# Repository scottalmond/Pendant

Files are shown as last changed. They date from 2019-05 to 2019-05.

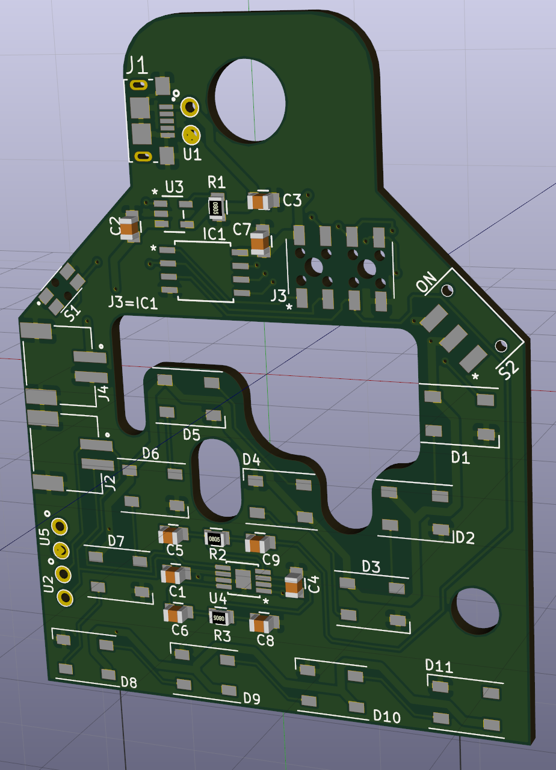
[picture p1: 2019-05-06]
src/layout_front.png

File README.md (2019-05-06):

# Pendant

The purpose of this project is to develop a piece of artisan eletronics to serve as a prize for an eletronics competition.  The design consists of a PCB and 3D-printed case.  The CAD model for the case has been excluded from this project because it incorporates proprietary elements.

Development Tools
Arduino IDE
KiCAD
FreeCAD

The J3 header has a 1:1 pinout matching the Attiny85 processor.
Instructions for programming the Attiny85 using an Arduino is documented at the start of the Arduino code.  Once the Arduino has been programmed with the ArduinoAsISP program, it can be connected to the J3 programming header using the following connections:
https://hackster.imgix.net/uploads/cover_image/file/50546/Programming%20ATtiny85%20with%20Arduino%20Uno_bb.png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

License
CC BY 4.0: Scott Almond
https://creativecommons.org/licenses/by/4.0/

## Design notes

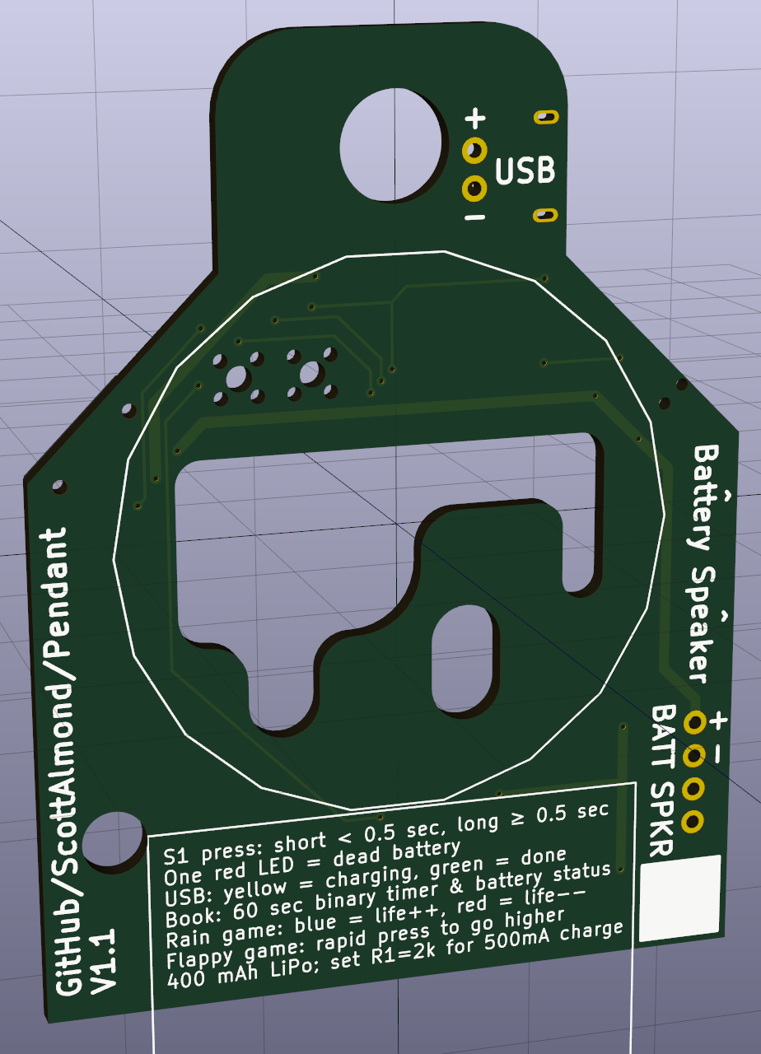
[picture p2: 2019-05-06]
src/layout_rear.png

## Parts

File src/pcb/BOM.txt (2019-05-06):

For Qty 25
Processor             25x  $1.07ea@25  ATTINY85-20SU-ND       https://www.digikey.com/product-detail/en/ATTINY85-20SU/ATTINY85-20SU-ND/735470
DC Power Switch       25x  $0.56ea@25  JS102011SAQN           https://www.digikey.com/product-detail/en/JS102011SAQN/401-1999-1-ND/1640114
Button                25x  $0.37ea@25  P16765CT-ND            https://www.digikey.com/product-detail/en/EVQ-P7C01P/P16765CT-ND/4429458
Battery 400mAh        25x  $4.95ea@25  PRT-13851              https://www.digikey.com/product-detail/en/PRT-13851/1568-1493-ND/6605199
Speaker 8ohm          25x  $2.49ea@25  SP-4005-1              https://www.digikey.com/product-detail/en/SP-4005-1/433-1152-ND/6562951
Audio Amp             25x  $0.79ea@25  TPA6211A1DGNR          https://www.digikey.com/product-detail/en/TPA6211A1DGNR/296-26889-1-ND/2255205
LED, 10 pack         30x   $5.95ea@1   2759                   https://www.digikey.com/product-detail/en/adafruit-industries-llc/2759/1528-1710-ND/6134707
Battery Charge Chip   25x  $0.48ea@25  MCP73831T-2ACI/OT      https://www.digikey.com/product-detail/en/microchip-technology/MCP73831T-2ACI-OT/MCP73831T-2ACI-OTCT-ND/1979802
Program Header 2x4    25x  $1.17ea@1   M20-7810445            https://www.digikey.com/product-detail/en/M20-7810445/952-3209-ND/6564945
JST Header           50x   $0.55ea@10  S2B-PH-SM4-TB(LF)(SN)  https://www.digikey.com/product-detail/en/jst-sales-america-inc/S2B-PH-SM4-TB-LF-SN/455-1749-1-ND/926846
USB Micro Header      25x  $0.38ea@25  10118193-0001LF        https://www.digikey.com/product-detail/en/10118193-0001LF/609-4616-1-ND/2785380
Resistor 805
Capacitor 805

to do:
make schematic symbol for LED
schematic/symbol for audio amp
li-ion charger

300px = 500 mA
448 px = 400 mA
1036 px = 0 mA

1974 px = 2 kOhms
1998 px = >? ohms
2262 px = 17 kOhms

288
(1998-1974)/(x-2)=(2262-1974)/(17-2)
(1998-1974)*(17-2)=(x-2)*(2262-1974)
(1998-1974)*(17-2)/(2262-1974)=(x-2)
(1998-1974)*(17-2)/(2262-1974)+2=x
3.25

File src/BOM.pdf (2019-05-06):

Sheet1

For production run of 25 units

Function | Qty | Unit Price | Extended Price Part #
JST Header | 50 | 0.55 | 27.50 S2B-PH-SM4-TB(LF)(SN)
LED, 10 pack | 30 | 5.95 | 178.50 2759, SK6812RGBW
Processor | 25 | 1.07 | 26.75 ATTINY85-20SU-ND
DC Power Switch | 25 | 0.56 | 14.00JS102011SAQN
Button | 25 | 0.37 | 9.25 EVQ-P7C01P
Battery 400mAh | 25 | 4.95 | 123.75 PRT-13851
Speaker 8ohm | 25 | 2.49 | 62.25 SP-4005-1
Audio Amp | 25 | 0.79 | 19.75 TPA6211A1DGNR
Battery Charge Chip | 25 | 0.48 | 12.00 MCP73832T-2ACI/OT
Program Header 2x4 | 25 | 1.17 | 29.25 M20-7810445
USB Micro Header | 25 | 0.38 | 9.5010118193-0001LF
3.9k Ohms | 100 | 0.0085 | 0.85 RMCF0805JT3K90
27k Ohms | 100 | 0.0085 | 0.85 RMCF0805JT27K0
4.7 uF, ~4 micro | 100 | 0.044 | 4.40 CL21A475KQFNNNG
4.7 nF, ~4 nano | 100 | 0.0238 | 2.38 CL21B472KBANNNC
1 uF, 1 micro | 100 | 0.0352 | 3.52 CL21B105KAFNNNE
100 nF, nano | 100 | 0.0558 | 5.58 CC0805KRX7R9BB104
47 uF, ~40 micro | 25 | 0.339 | 8.48 GRM21BC80G476ME15L
Unit Cost | | | 21.54
Total Price | | | 538.56

URL
https://www.digikey.com/product-detail/en/jst-sales-america-inc/S2B-PH-SM4-TB-LF-SN/455-1749-1-ND/926846https://www.digikey.com/product-detail/en/adafruit-industries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

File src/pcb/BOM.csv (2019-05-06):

For production run of 25 units
Function | Qty | Unit Price | Extended Price | Part # | URL
JST Header | 50 | 0.55 | 27.50 | S2B-PH-SM4-TB(LF)(SN) | https://www.digikey.com/product-detail/en/jst-sales-america-inc/S2B-PH-SM4-TB-LF-SN/455-1749-1-ND/926846
LED, 10 pack | 30 | 5.95 | 178.50 | 2759, SK6812RGBW | https://www.digikey.com/product-detail/en/adafruit-industries-llc/2759/1528-1710-ND/6134707
Processor | 25 | 1.07 | 26.75 | ATTINY85-20SU-ND | https://www.digikey.com/product-detail/en/ATTINY85-20SU/ATTINY85-20SU-ND/735470
DC Power Switch | 25 | 0.56 | 14.00 | JS102011SAQN | https://www.digikey.com/product-detail/en/JS102011SAQN/401-1999-1-ND/1640114
Button | 25 | 0.37 | 9.25 | EVQ-P7C01P | https://www.digikey.com/product-detail/en/EVQ-P7C01P/P16765CT-ND/4429458
Battery 400mAh | 25 | 4.95 | 123.75 | PRT-13851 | https://www.digikey.com/product-detail/en/PRT-13851/1568-1493-ND/6605199
Speaker 8ohm | 25 | 2.49 | 62.25 | SP-4005-1 | https://www.digikey.com/product-detail/en/SP-4005-1/433-1152-ND/6562951
Audio Amp | 25 | 0.79 | 19.75 | TPA6211A1DGNR | https://www.digikey.com/product-detail/en/TPA6211A1DGNR/296-26889-1-ND/2255205
Battery Charge Chip | 25 | 0.48 | 12.00 | MCP73832T-2ACI/OT | https://www.digikey.com/product-detail/en/microchip-technology/MCP73832T-2ACI-OT/MCP73832T-2ACI-OTCT-ND/1979805
Program Header 2x4 | 25 | 1.17 | 29.25 | M20-7810445 | https://www.digikey.com/product-detail/en/M20-7810445/952-3209-ND/6564945
USB Micro Header | 25 | 0.38 | 9.50 | 10118193-0001LF | https://www.digikey.com/product-detail/en/10118193-0001LF/609-4616-1-ND/2785380
3.9k Ohms | 100 | 0.0085 | 0.85 | RMCF0805JT3K90 | https://www.digikey.com/product-detail/en/stackpole-electronics-inc/RMCF0805JT3K90/RMCF0805JT3K90CT-ND/1942569
27k Ohms | 100 | 0.0085 | 0.85 | RMCF0805JT27K0 | https://www.digikey.com/product-detail/en/stackpole-electronics-inc/RMCF0805JT27K0/RMCF0805JT27K0CT-ND/1942583
4.7 uF, ~4 micro | 100 | 0.044 | 4.40 | CL21A475KQFNNNG | https://www.digikey.com/product-detail/en/samsung-electro-mechanics/CL21A475KQFNNNG/1276-6465-1-ND/5958093
4.7 nF, ~4 nano | 100 | 0.0238 | 2.38 | CL21B472KBANNNC | https://www.digikey.com/product-detail/en/samsung-electro-mechanics/CL21B472KBANNNC/1276-1155-1-ND/3889241
1 uF, 1 micro | 100 | 0.0352 | 3.52 | CL21B105KAFNNNE | https://www.digikey.com/product-detail/en/samsung-electro-mechanics/CL21B105KAFNNNE/1276-1066-1-ND/3889152
47 uF, ~40 micro | 25 | 0.339 | 8.48 | GRM21BC80G476ME15L | https://www.digikey.com/product-detail/en/murata-electronics-north-america/GRM21BC80G476ME15L/490-9954-1-ND/5026421
Unit Cost |  |  | 21.32
Total Price |  |  | 532.98

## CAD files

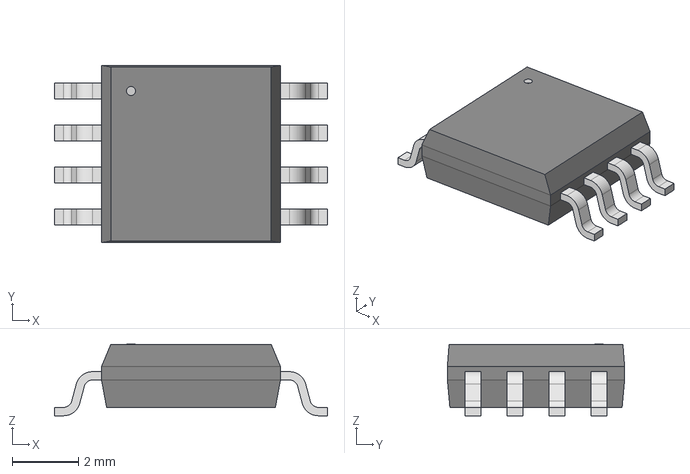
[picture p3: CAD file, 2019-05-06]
src/pcb/footprints/UL_ATTINY8520SU/STEP/8S2.step
8.26 x 5.36 x 2.16 mm

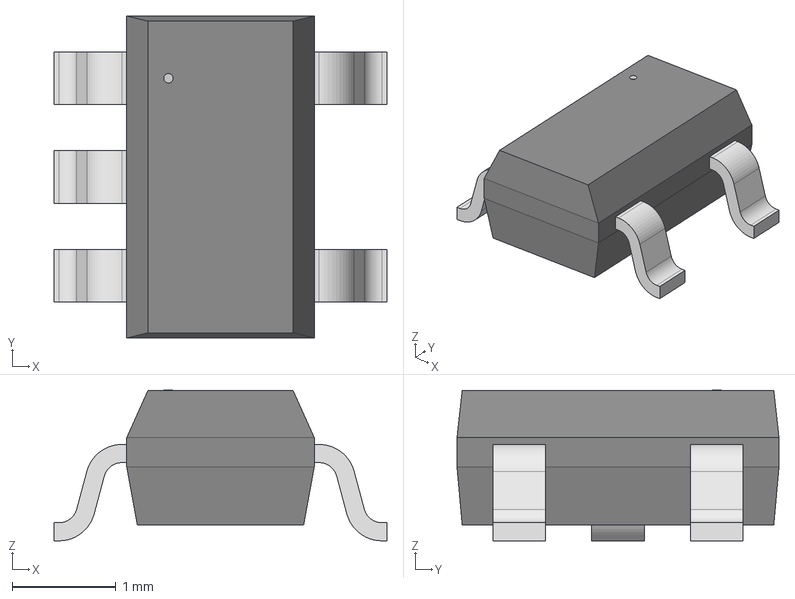
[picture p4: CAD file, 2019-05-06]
src/pcb/footprints/UL_MCP73831T2ACIOT/STEP/SOT-23-5_MC.step
3.20 x 3.10 x 1.45 mm

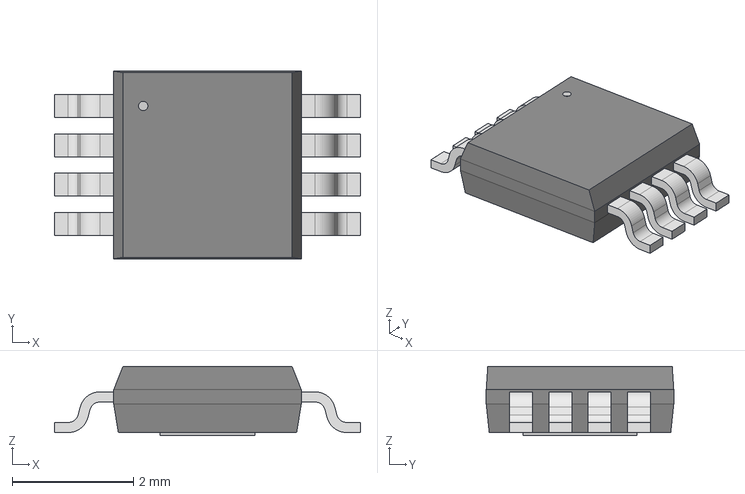
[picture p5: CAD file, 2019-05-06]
src/pcb/footprints/UL_TPA6211A1DGNR/STEP/DGN8_1P89X1P57-L.step
5.05 x 3.10 x 1.15 mm

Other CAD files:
src/pcb/footprints/UL_ATTINY8520SU/STEP/8S2-L.step
src/pcb/footprints/UL_MCP73831T2ACIOT/STEP/SOT-23-5_MC-M.step
src/pcb/footprints/UL_TPA6211A1DGNR/STEP/DGN8_1P89X1P57-M.step
src/pcb/footprints/UL_ATTINY8520SU/STEP/8S2-M.step
src/pcb/footprints/UL_MCP73831T2ACIOT/STEP/SOT-23-5_MC-L.step
src/pcb/footprints/UL_TPA6211A1DGNR/STEP/DGN8_1P89x1P57.step

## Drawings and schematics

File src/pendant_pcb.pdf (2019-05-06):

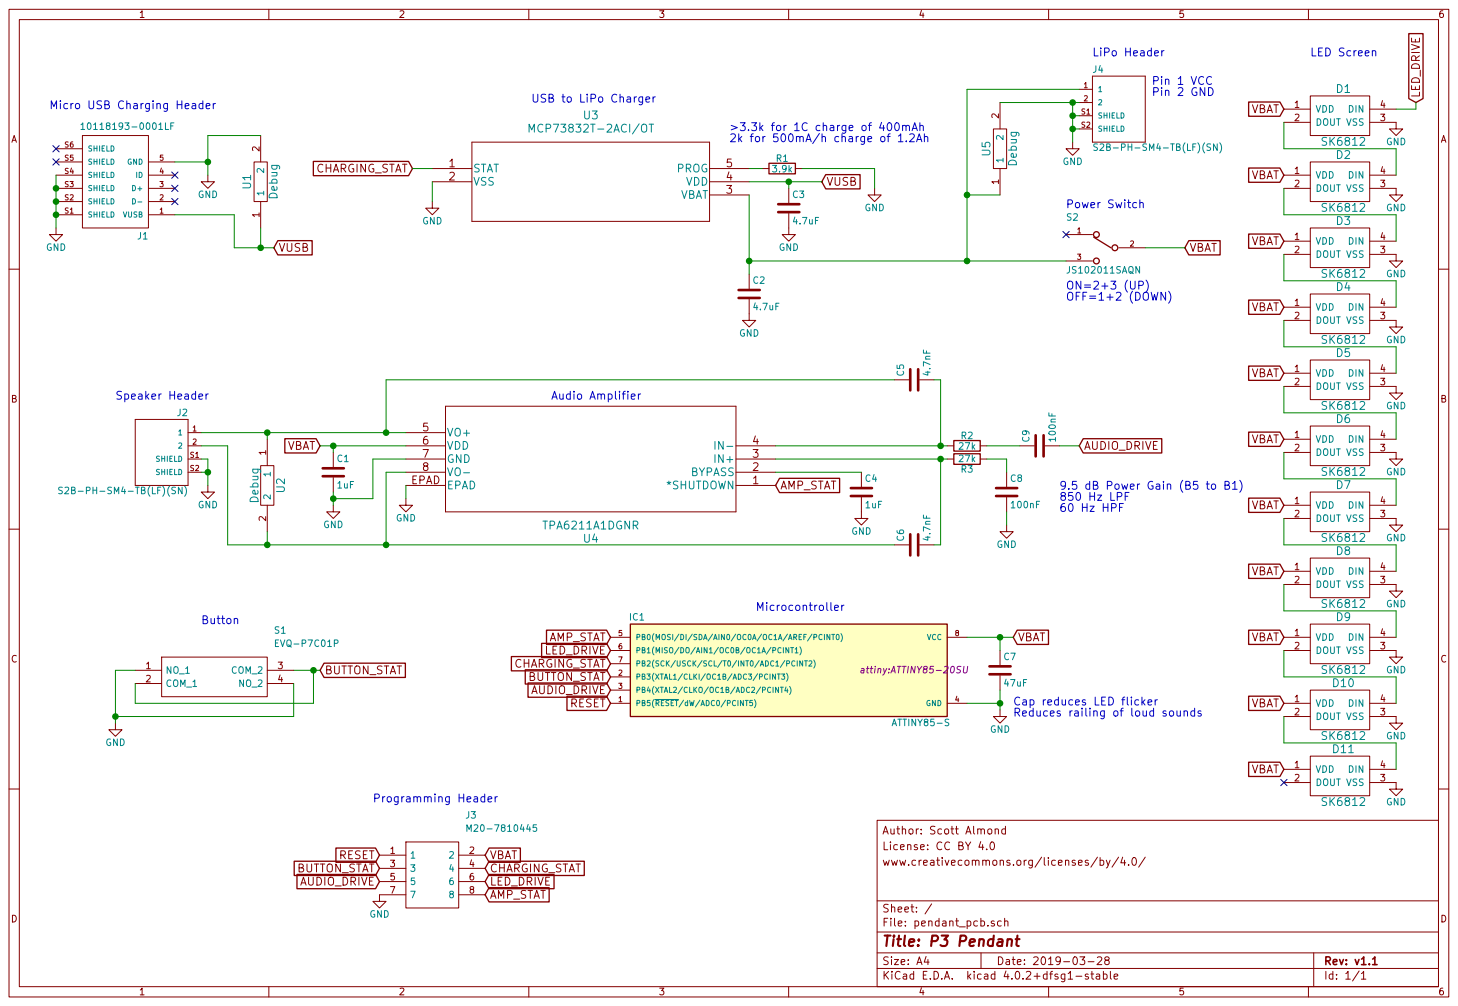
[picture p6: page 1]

LiPo Header Power Switch

USB to LiPo Charger

VBAT VBAT GND VBAT

Reduces railing of loud sounds R3

9.5 dB Power Gain (B5 to B1) 850 Hz LPF
60 Hz HPF

File: pendant_pcb.sch Sheet: / www.creativecommons.org/licenses/by/4.0/ License: CC BY 4.0 Author: Scott Almond

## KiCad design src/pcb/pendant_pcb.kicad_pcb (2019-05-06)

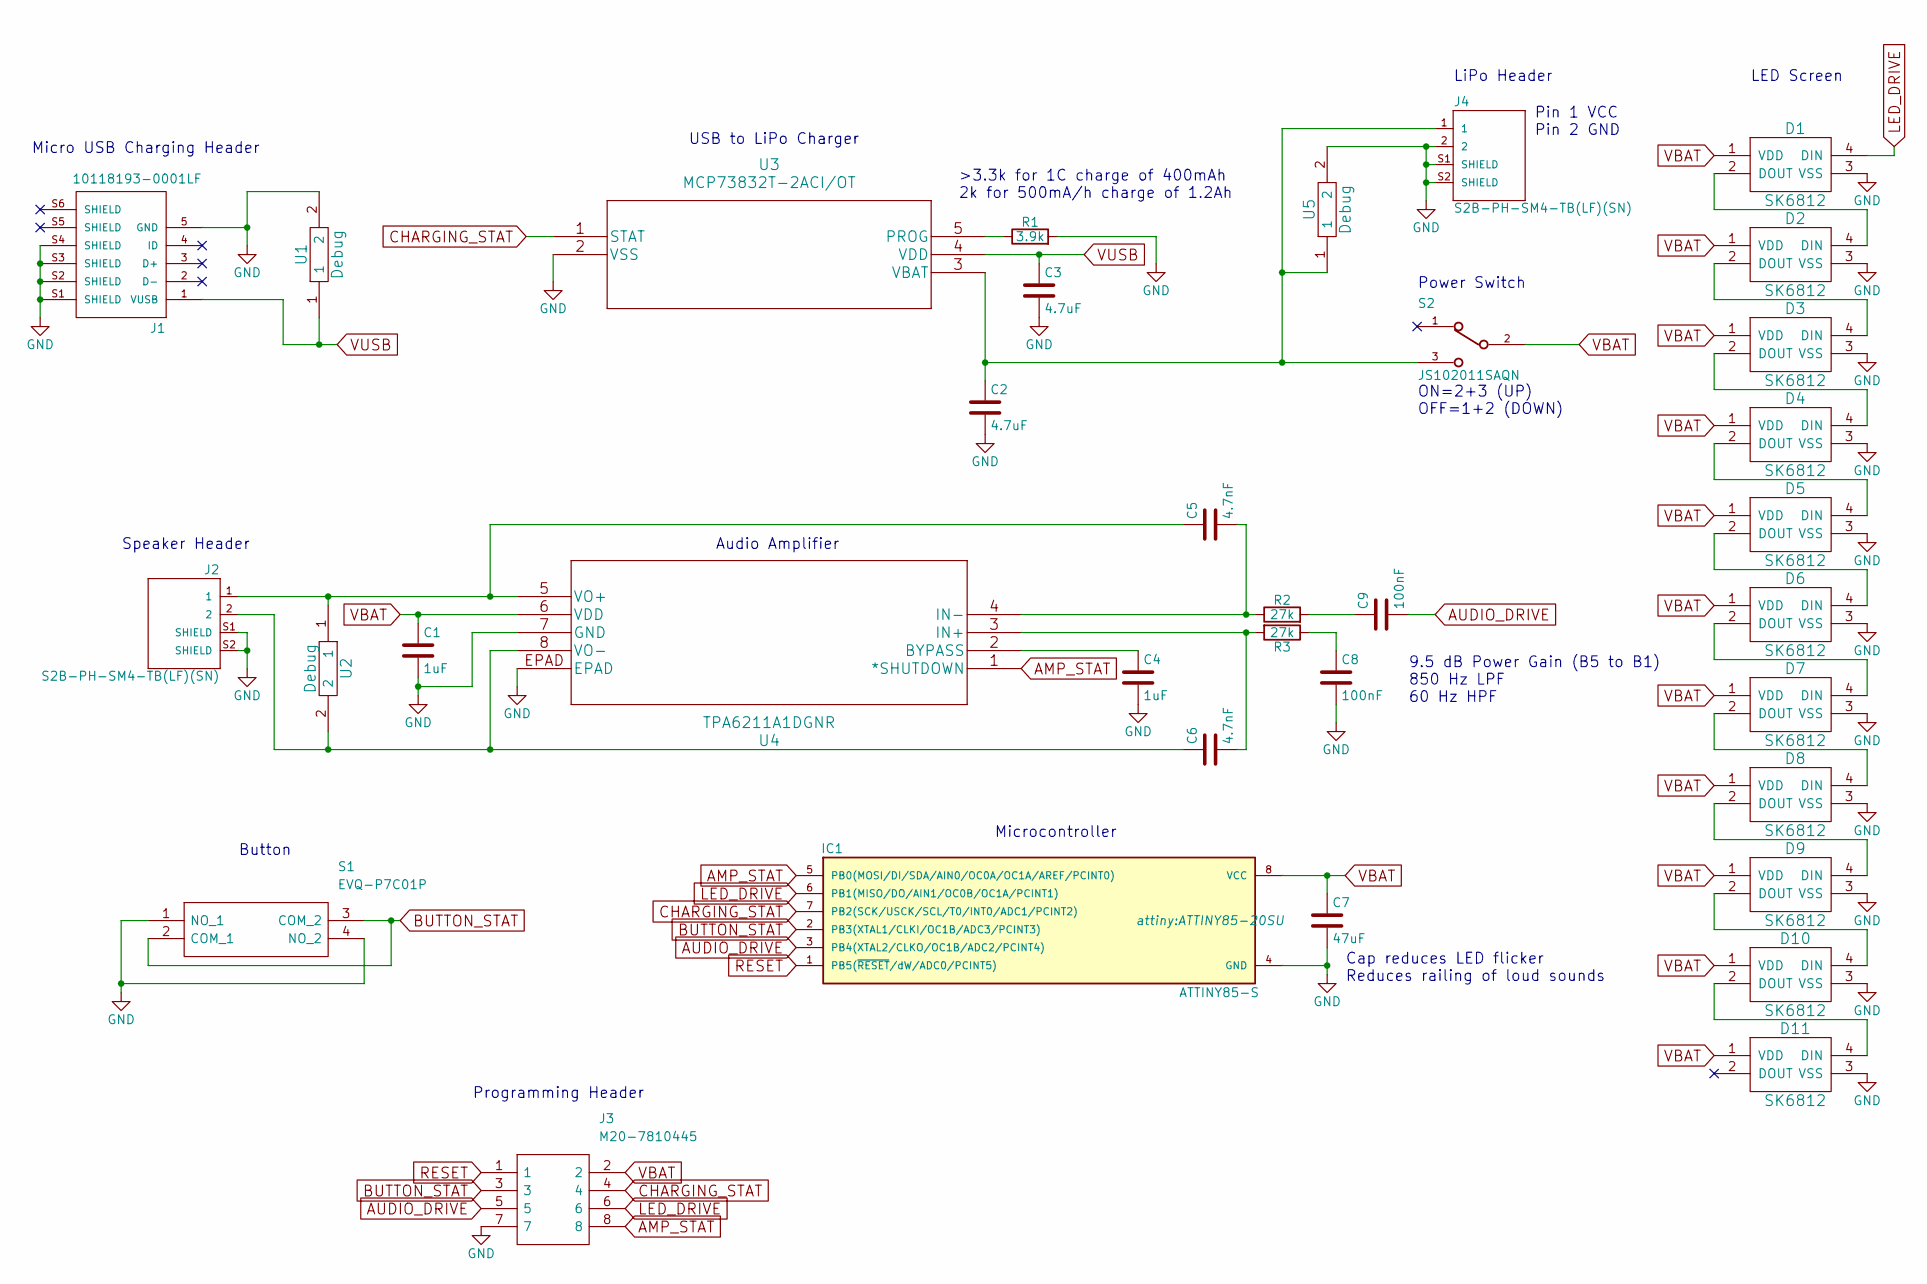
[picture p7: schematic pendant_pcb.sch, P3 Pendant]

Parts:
C1, C4: 1uF; C_0805
C2, C3: 4.7uF; C_0805
C5, C6: 4.7nF; C_0805
C7: 47uF; C_0805
C8, C9: 100nF; C_0805
D1, D2, D3, D4, D5, D6, D7, D8, D9, D10, D11: SK6812; LED_SK6812_PLCC4_5.0x5.0mm_P3.2mm
IC1: ATTINY85-S; ATTINY85-20SU
J1: 10118193-0001LF; FCI_10118193-0001LF
J2, J4: S2B-PH-SM4-TB(LF)(SN); JST_S2B-PH-SM4-TB(LF)(SN)
J3: M20-7810445; M207810445; Mouser Part Number 855-M20-7810445
R1: 3.9k; R_0805
R2, R3: 27k; R_0805
S1: EVQ-P7C01P; EVQP7C01P; Manufacturer_Part_Number EVQ-P7C01P; Mouser Part Number 667-EVQP7C01P
S2: JS102011SAQN; SW_JS102011SAQN
U1, U2, U5: Debug; Debug_2p
U3: MCP73832T-2ACI/OT; MCP73831T-2ACI&slash_OT
U4: TPA6211A1DGNR

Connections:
AMP_STAT: IC1.5 (PB0(MOSI/DI/SDA/AIN0/OC0A/OC1A/AREF/PCI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), J3.8, U4.1 (*SHUTDOWN)
AUDIO_DRIVE: C9.2, IC1.3 (PB4(XTAL2/CLKO/OC1B/ADC2/PCINT4)), J3.5
BUTTON_STAT: IC1.2 (PB3(XTAL1/CLKI/OC1B/ADC3/PCINT3)), J3.3, S1.2 (COM_1), S1.3 (COM_2)
CHARGING_STAT: IC1.7 (PB2(SCK/USCK/SCL/T0/INT0/ADC1/PCINT2)), J3.4, U3.1 (STAT)
GND: C1.2, C2.2, C3.2, C4.2, C7.2, C8.2, D1.3 (VSS), D2.3 (VSS), D3.3 (VSS), D4.3 (VSS), D5.3 (VSS), D6.3 (VSS), D7.3 (VSS), D8.3 (VSS), D9.3 (VSS), D10.3 (VSS), D11.3 (VSS), IC1.4 (GND), J1.5 (GND), J1.S1 (SHIELD), J1.S2 (SHIELD), J1.S3 (SHIELD), J1.S4 (SHIELD), J2.S1 (SHIELD), J2.S2 (SHIELD), J3.7, J4.2, J4.S1 (SHIELD), J4.S2 (SHIELD), R1.2, S1.1 (NO_1), S1.4 (NO_2), U1.2, U3.2 (VSS), U4.7 (GND), U4.EPAD, U5.2
LED_DRIVE: D1.4 (DIN), IC1.6 (PB1(MISO/DO/AIN1/OC0B/OC1A/PCINT1)), J3.6
unnamed: C2.1, J4.1, S2.3, U3.3 (VBAT), U5.1
unnamed: C4.1, U4.2 (BYPASS)
unnamed: C5.1, J2.1, U2.1, U4.5 (VO+)
unnamed: C5.2, R2.1, U4.4 (IN-)
unnamed: C6.1, J2.2, U2.2, U4.8 (VO-)
unnamed: C6.2, R3.2, U4.3 (IN+)
unnamed: C8.1, R3.1
unnamed: C9.1, R2.2
unnamed: D1.2 (DOUT), D2.4 (DIN)
unnamed: D2.2 (DOUT), D3.4 (DIN)
unnamed: D3.2 (DOUT), D4.4 (DIN)
unnamed: D4.2 (DOUT), D5.4 (DIN)
unnamed: D5.2 (DOUT), D6.4 (DIN)
unnamed: D6.2 (DOUT), D7.4 (DIN)
unnamed: D7.2 (DOUT), D8.4 (DIN)
unnamed: D8.2 (DOUT), D9.4 (DIN)
unnamed: D10.2 (DOUT), D11.4 (DIN)
unnamed: D9.2 (DOUT), D10.4 (DIN)
unnamed: R1.1, U3.5 (PROG)
RESET: IC1.1 (PB5(~RESET~/dW/ADC0/PCINT5)), J3.1
VBAT: C1.1, C7.1, D1.1 (VDD), D2.1 (VDD), D3.1 (VDD), D4.1 (VDD), D5.1 (VDD), D6.1 (VDD), D7.1 (VDD), D8.1 (VDD), D9.1 (VDD), D10.1 (VDD), D11.1 (VDD), IC1.8 (VCC), J3.2, S2.2, U4.6 (VDD)
VUSB: C3.1, J1.1 (VUSB), U1.1, U3.4 (VDD)

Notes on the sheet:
Pin 1 VCC Pin 2 GND
Programming Header
LiPo Header
Power Switch
USB to LiPo Charger
Audio Amplifier
Micro USB Charging Header
Speaker Header
LED Screen
ON=2+3 (UP) OFF=1+2 (DOWN)
Button
Microcontroller
>3.3k for 1C charge of 400mAh 2k for 500mA/h charge of 1.2Ah
9.5 dB Power Gain (B5 to B1) 850 Hz LPF 60 Hz HPF
Cap reduces LED flicker Reduces railing of loud sounds

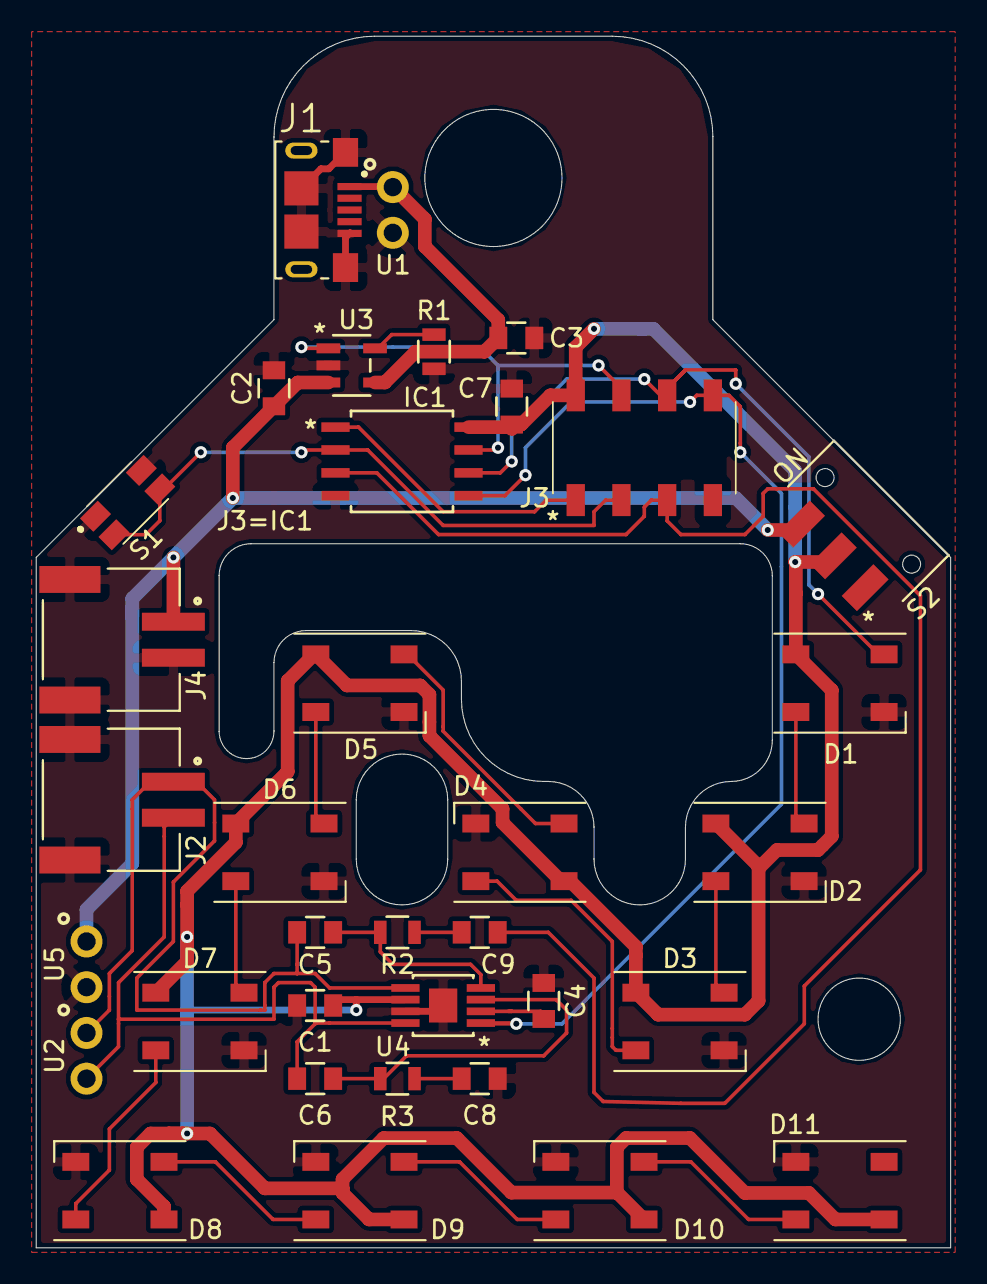
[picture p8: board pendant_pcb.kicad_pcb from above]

Board: 2 copper layers, 50.8 x 67.3 mm, 35 parts (0 on the bottom side), 28 nets.

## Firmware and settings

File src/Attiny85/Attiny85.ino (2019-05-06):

//Step 1. Program an Arduino with the ArduinoISP program: File >> Examples >> 11.ArduinoISP >> ArduinoISP
//Step 2. Connect the ISP Arduino to the J3 header (the J3 pinout matches the Attiny pinout, note the white circle adjacent to pin 1):
//  https://hackster.imgix.net/uploads/cover_image/file/50546/Programming%20ATtiny85%20with%20Arduino%20Uno_bb.png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
//Step 3. Acquire Attiny core through steps here: https://create.arduino.cc/projecthub/arjun/programming-attiny85-with-arduino-uno-afb829
//Step 4. Enable Arduino IDE to retain EEPROM values between reflashing
//  File >> Preferences >> (Note "preferences" location at bottom of window)
//  Navigate to "preferences" folder
//  From there, navigate to /packages/attiny/hardware/avr/1.0.2/
//  AT C:\Program Files (x86)\Arduino\hardware\arduino\avr\boards.txt
//  WAS: ATtinyX5.menu.clock.internal8.bootloader.high_fuses=0xdf
//  IS:  ATtinyX5.menu.clock.internal8.bootloader.high_fuses=0xd7
//  ( Core settings ref https://forum.arduino.cc/index.php?topic=393434.0 )
//  ( EEPROM fuse ref https://forum.arduino.cc/index.php?topic=278083.0 )
//Step 5. Restart Arduino IDE
//Step 6. Burn bootloader, Attiny85, 8 MHz, Internal
//  FYI, this may require either an FTDI or another Arduino to act as an intermediate programmer, ref. IDE >> File >> Examples >> 11.ArduinoISP
//  https://create.arduino.cc/projecthub/arjun/programming-attiny85-with-arduino-uno-afb829
//Step 7. Set BURN_EEPROM to 1 and upload program
//Step 8. Set BURN_EEPROM to 0 and upload program
#define BURN_EEPROM 0

// ---- Libraries ----
// -- LEDs --
#include <Adafruit_NeoPixel.h> //LEDs
#ifdef __AVR__
  #include <avr/power.h>
#endif

// -- Top Level IO --
const byte PIN_LED=1;//D1 is physical pin 6
const byte LED_COUNT=11;
neoPixelType STRIP_TYPE=NEO_GRBW + NEO_KHZ800;
Adafruit_NeoPixel strip = Adafruit_NeoPixel(LED_COUNT, PIN_LED, STRIP_TYPE);

// -- EEPROM Sound --
const word EEPROM_ADDRESS_SHORT_CHARACTER=0;
const byte SHORT_SOUND_CHARACTER_COUNT=6;//ref. "Tune" character list
const byte SHORT_SOUND_COUNT=7;
const byte SOUND_PRESS_COUNT_ROOT=8;//~2 seconds of 1/8 tick counts
const byte SOUND_PRESS_COUNT_CHAPTER=1;//1/8 second press is enough to go to next chapter
const word EEPROM_ADDRESS_AUDIO_FLAG=EEPROM_ADDRESS_SHORT_CHARACTER+SHORT_SOUND_CHARACTER_COUNT*SHORT_SOUND_COUNT;
const word AUDIO_FLAG_CHARACTER_COUNT=34;
const word EEPROM_ADDRESS_AUDIO_SONG=EEPROM_ADDRESS_AUDIO_FLAG+AUDIO_FLAG_CHARACTER_COUNT;//76
const word AUDIO_SONG_CHARACTER_COUNT=176;
const word EEPROM_TUNE_LENGTH=EEPROM_ADDRESS_AUDIO_SONG+AUDIO_SONG_CHARACTER_COUNT-EEPROM_ADDRESS_SHORT_CHARACTER; //number of characters in EEPROM for sound, 252

// -- EEPROM LED Backgrounds --
const byte BACKGROUND_COUNT=4;
const word EEPROM_BASE_ADDRESS_BACKGROUND=EEPROM_ADDRESS_AUDIO_SONG+AUDIO_SONG_CHARACTER_COUNT;
const word EEPROM_ADDRESS_BACKGROUND_FLAG=    EEPROM_BASE_ADDRESS_BACKGROUND+0*LED_COUNT*sizeof(uint32_t);
const word EEPROM_ADDRESS_BACKGROUND_RAINBOW= EEPROM_BASE_ADDRESS_BACKGROUND+1*LED_COUNT*sizeof(uint32_t);
const word EEPROM_ADDRESS_BACKGROUND_TIMER=   EEPROM_BASE_ADDRESS_BACKGROUND+2*LED_COUNT*sizeof(uint32_t);
const word EEPROM_ADDRESS_BACKGROUND_BOOK=    EEPROM_BASE_ADDRESS_BACKGROUND+3*LED_COUNT*sizeof(uint32_t);//and sound
const word EEPROM_ADDRESS_BACKGROUND_BLACK=512;//invalid value, EEROM only has bytes 0-511
const word BACKGROUND_UNUSED_BYTES=sizeof(uint32_t)*4;//4 colors unused at end of last book

// -- EEPROM Game Backgrounds --
const byte FRAME_COUNT_ACID=24;
const byte FRAME_COUNT_FLAPPY=12;
const word EEPROM_ADDRESS_GAME_RAIN=EEPROM_BASE_ADDRESS_BACKGROUND+sizeof(uint32_t)*BACKGROUND_COUNT*LED_COUNT-BACKGROUND_UNUSED_BYTES;
const word EEPROM_ADDRESS_GAME_FLAPPY=EEPROM_ADDRESS_GAME_RAIN+FRAME_COUNT_ACID*sizeof(word);
const word EEPROM_ADDRESS_UNUSED_BEGIN=EEPROM_ADDRESS_GAME_FLAPPY+FRAME_COUNT_FLAPPY*sizeof(word);//beginning of unallocated space in EEPROM

#if BURN_EEPROM==0

// ---- State Machines ----
unsigned long start_button_ms=0xAFFFFFFF;//in chapter state machine, this is the start time of the button press, in the book-selection state machine, this is the end time of the button press
byte book_index=0;//TODO default to 0
const byte BOOK_COUNT=7; // there are 7 books: 0.home, 1.timer/battery, 2.song, 3.monotones, 4.acid rain game, 5.flappy bird game, 6.USA flag
const byte NO_STATE_CHANGE=0;
const byte GO_TO_NEXT_CHAPTER=1;
const byte GO_TO_ROOT=2;//jump out of current book and select new book

// -- Button --
const byte PIN_BUTTON=3; //D3 is physical pin 2 https://cdn.sparkfun.com/r/600-600/assets/f/8/f/d/9/52713d5b757b7fc0658b4567.png
const byte LONG_PRESS_SMS=9; //1=0.001seconds, 9=0.512 seconds, etc.  Pressing button for < this value interacts with or changes chapters, SMS = Shifted value and expressed in MilliSeconds
//holding button longer than this changes the book selection
const byte TIMEOUT_SMS=3; //0=0.255 seconds, 3=2.048 seconds, 4=4.096 sec, etc.  If no user input is received within this time frame, the state machine times out and moves on to the next state (like entering the selected book)
const byte DEBOUNCE_MS=50; //disregard button transitions that occur within this interval of another button transition
const byte BLINK_LED_SMS=8; //0=0.002 sec (500 Hz), 6=0.128 sec (7.8 Hz)

// -- Home --
const byte HUE_DELAY_MS=10;//milliseconds between each successive (slightly different) color display
uint32_t home_hue=strip.Color(255,0,0);
byte home_brightness=255;//20;//TODO default max 255

// -- Sound --
//FYI: pin D4 used for waveform output, physical pin 3
bool is_sound_enabled=false;//flag to track the status of whether sound is enabled or not
byte sound_press_count=0;//number of 1/8 sec ticks encountered while button was down
byte sound_state=NO_STATE_CHANGE;//use different state machine for button presses during audio playback due to chalenges with millis() (counts 4x speed), slow clock speed (1/8 sec interrupts), etc
const byte PIN_AMPLIFIER=0; //D0 is physical pin 5

// -- Acid Rain Game --
byte MAX_LIVES_GAME=9;
unsigned long const COLUMN_DELTA_GAME=0b01000100100001100110001001011010;//every two bits is a number 0-2, representing which column relative to the current rain column, that will have rain next
//used as a "sudo-random number generator"

// -- Hidden Chapters --
word MIN_BATTERY_MILLIVOLTS=3000;//2.9 V minimum trips battery warning
byte PIN_CHARGING=2; //D2 is physical pin 7, detect when plugged into USB
byte LOW_POWER_LED_BRIGHTNESS=3;//brightness between 0 (min) and 255 (max) to display indicator that battery is dying or charging
byte battery_memory;
byte charge_state=0x40;// charge_state>=0x80 is charging (MSB=1), else NOT charging

void setup() {
  reset_battery_memory();
  strip.begin();
  strip.setBrightness(home_brightness);
  strip.show();//clear LEDs
  pinMode(PIN_CHARGING,INPUT_PULLUP);//detect when external charge circuit is activated, LOW is charging, HIGH is fully charged, floating is charging
  pinMode(PIN_BUTTON,INPUT_PULLUP);//user button input, HIGH is button_down, LOW is button_up
  pinMode(PIN_AMPLIFIER,OUTPUT);//external amplifier enable pin, HIGH is enabled, LOW is disabled
  enable_amplifier(false);
}

//top level state machine to display book selection
void loop() {
  display_book(book_index);
  while(is_button_down()) start_button_ms=millis();
  while(!is_button_down())
  {
    display_book(book_index);//display 2 second count down animation to book being selected
    if((millis()-start_button_ms)>2048) run_chapter(book_index);//run chapter (upon chapter exit, the button will be down for >0.5 sec)
  }
  if((millis()-start_button_ms)>DEBOUNCE_MS) book_index=(book_index+1)%BOOK_COUNT;//select next book
  start_button_ms=millis()-1;
}

//due to internal pull-up, button is HIGH when unpressed, LOW when pressed
bool is_button_down(){ return !digitalRead(PIN_BUTTON); }

//root menu display: 1-7 LEDs ON white and one LED set to one of seven colors
void display_book(byte book_index)
{
  uint8_t white=((start_button_ms-millis())>>TIMEOUT_SMS);//over the span of 2.048 seconds (0.255<<3), transition from 0xFF white to 0x00 white
  uint32_t book_color=EEPROMReadLong(EEPROM_ADDRESS_BACKGROUND_BOOK+sizeof(uint32_t)*book_index);
  for(byte iter=0;iter<LED_COUNT;iter++)
  {
    if(iter<BOOK_COUNT)
    {
      if(iter<=book_index) strip.setPixelColor(BOOK_COUNT-1-iter,strip.Color(0,0,0,white));
      else strip.setPixelColor(BOOK_COUNT-1-iter,strip.Color(0,0,0,0));//black
    }else{
      strip.setPixelColor(iter,book_color);//display solid color bar at bottom to reinforce user understanding of chapter selection
    }
  }
  strip.show();
}

//execute one chapter
//returns when the button has been (and still is) held down for an extended period of time
void run_chapter(byte book_index)
{
  start_button_ms=0;
  sound_state=NO_STATE_CHANGE;
  sound_press_count=0;
  switch(book_index)
  {
    default:
    case 0: book_home(); break;
    case 1: book_time_and_battery(); break;//TODO: combine bottom four LEDs of time to show battery, with top 7 LEDs to show time counter
    case 2: chapter_video(false); break;//rainbow tune
    case 3: book_sound(); break;//theme sounds
    case 4: book_game(true); break;//acid rain
    case 5: book_game(false); break;//flappy bird
    case 6: chapter_video(true); break;//flag
  }
  stop_sound();
}

//interpret what the user wants to do by reading the button state
byte get_next_chapter_state()
{
  book_battery_state();
  unsigned long time_held_ms=millis()-start_button_ms;
  if(is_button_down())
  {
    if(start_button_ms==0) start_button_ms=millis();
    else if(time_held_ms>>LONG_PRESS_SMS) return GO_TO_ROOT;
  }else{
    if(start_button_ms!=0 and time_held_ms>DEBOUNCE_MS)
    {
      start_button_ms=0;
      return GO_TO_NEXT_CHAPTER;
    }
  }
  return NO_STATE_CHANGE;
}
#endif

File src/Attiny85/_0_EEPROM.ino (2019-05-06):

#include <EEPROM.h> //EEPROM

#if BURN_EEPROM!=0
const byte DEBUG_BRIGHTNESS=20;//how bright to display the verification stage
const byte PIN_DEBUG=3;//input button to change state of debugger, illuminate the debugger LED when done flashing EEPROM

const PROGMEM char Tune[EEPROM_TUNE_LENGTH]="A(^^)\0"
                                            "C(^^)\0"
                                            "G(^^)\0"
                                            "A(CG)\0" //6
                                            "A(C^)\0"
                                            "C(G^)\0"
                                            "A(G^)\0"
                                            "4,CCD6,b2,C4,DEEF6,e2,d4,cDcb12,C\0"//34 characters
                                            "C(-1:C)Fe2,dE4,F(-1:D)2,eF4,A(-1:G)g2,f(-1:F)eF(-1:E)G4,f(-1:D)e(-1:C)"//176 char 
                                            "2,d(-2:B)Edc4,b(-2:G)Gc(-1:C)Fe2,dE4,F(-1:D)2,eF4,A(-1:G)g"
                                            "2,A(-1:F)gA(-1:E)Cb(-1:G)gB(-1:B)D4,c(-1:C)g8,C\0";

const uint32_t BACKGROUND[BACKGROUND_COUNT][LED_COUNT]={{
  strip.Color(  1,  2,  3,255),//flag https://www.legion.org/flag/questions-answers/91472/what-are-exact-shades-colors-blue-and-red
  strip.Color(  0, 40,104,  0),
  strip.Color(  0,  0,  0,255),
  strip.Color(191, 10, 48,  0),
  strip.Color(191, 10, 48,  0),
  strip.Color(191, 10, 48,  0),
  strip.Color(  0,  0,  0,255),
  strip.Color(  0, 40,104,  0),
  strip.Color(  0, 40,104,  0),
  strip.Color(  0, 40,104,  0),
  strip.Color(  0, 40,104,  0)
},{
  strip.Color(255,  0,  0,  0),
  strip.Color(201, 54,  0,  0),
  strip.Color(146,109,  0,  0),
  strip.Color( 92,163,  0,  0),
  strip.Color( 37,218,  0,  0),
  strip.Color(  0,237, 18,  0),
  strip.Color(  0,183, 72,  0),
  strip.Color(  0,183, 72,  0),//steeple chase, reordered rainbow_11: bottom 4 (inc hue) are opposite order of first 7 (reverse hue)
  strip.Color(  0,237, 18,  0),
  strip.Color( 37,218,  0,  0),
  strip.Color( 92,163,  0,  0)
},{
  strip.Color(255,  0,  0,  0),//timer and game lives, rainbow_11
  strip.Color(255,140,  0,  0),
  strip.Color(230,255,  0,  0),
  strip.Color( 96,255,  0,  0),
  strip.Color(  0,255, 45,  0),
  strip.Color(  0,255,185,  0),
  strip.Color(  0,185,255,  0),
  strip.Color(  0, 45,255,  0),
  strip.Color( 96,  0,255,  0),
  strip.Color(230,  0,255,  0),
  strip.Color(255,  0,140,  0)
},{
  strip.Color(  0,  0,  0,255),//books white+rainbow_6
  strip.Color(255,  0,  0,  0),
  strip.Color(255,255,  0,  0),
  strip.Color(  0,255,  0,  0),
  strip.Color(  0,255,255,  0),
  strip.Color(  0,  0,255,  0),
  strip.Color(255,  0,255,  0),
  strip.Color(  0,  0,  0,  0),//unused
  strip.Color(  0,  0,  0,  0),
  strip.Color(  0,  0,  0,  0),
  strip.Color(  0,  0,  0,  0)
}};
//(4 bytes/led)*(11 leds/background)*(4 backgrounds) = 176 bytes.  176 bytes - (4 bytes/led)*(4 leds) = 160 bytes for led backgrounds

//acid game --> (2 bytes/frame)*(8 frames/level)*(3 levels) = 48 bytes
//flappy game-> (2 bytes/frame)*(4 frames/level)*(3 levels) = 24 bytes
//252+160+48+24= 484<512 by 28 bytes

const word frames_acid[FRAME_COUNT_ACID]={//MSB 5 bits of list index 0-7 are frame delays for level 0, list index 8-15 are frame delays for level 1, list index 16-23 are frame delays for level 2
  //LSB 11 bits for list index 0-7 are which LEDs are illuminated for left column acid rain, list index 8-15 is lightening in the center, list index 16-23 is right clumn rain
  0b0000000000000000,//acid rain frame 0 [0 sec, OFF], left rain and level 0 timing
  0b0100000000010000,//[0.5 sec, LED 4]
  0b0100000000010000,//[0.5 sec, LED 4]
  0b0100000000100000,//[0.5  sec, LED 5]
  0b0100000000100000,//[0.5  sec, LED 5]
  0b0100000001000000,//[0.5 sec, LED 6]
  0b0100000001000000,//[0.5 sec, LED 6]
  0b1000000010000000,//frame 7 [1 sec, LED 7]
  0b0000000000000000,//frame 8 [0 sec, OFF], begin middle (lightening) rain and level 1 timing
  0b0011000000001000,//[0.38 sec, LED 3]
  0b0011000000000000,//[0.38 sec, OFF]
  0b0011000000001000,//[0.38 sec, LED 3]
  0b0011000000000000,//[0.38 sec, OFF]
  0b0011000000001000,//[0.38 sec, LED 3]
  0b0011000000000000,//[0.38 sec, OFF]
  0b0110000100000000,//frame 15 [0.77 sec, LED 8]
  0b0000000000000000,//frame 16 [0 sec, OFF], right rain and level 2 timing
  0b0010000000000001,//[0.25 sec, LED 0]
  0b0010000000000001,//[0.25 sec, LED 0]
  0b0010000000000010,//[0.25 sec, LED 1]
  0b0010000000000010,//[0.25 sec, LED 1]
  0b0010000000000100,//[0.25 sec, LED 2]
  0b0010000000000100,//[0.25 sec, LED 2]
  0b0100001000000000//frame 23 [0.5 sec, LED 9]
};
/*const word frames_flappy[FRAME_COUNT_FLAPPY]={
  0b0100000000000000, //frame 1 [0.5 sec, OFF] bottom clear
  0b0100000000000111, //[0.5 sec, led 0, 1, 2]
  0b0100000000001000, //[0.5 sec, led 3]
  0b0100000001110000, //frame 3 [0.5 sec, led 4, 5, 6]
  0b0011010000000000, //frame 4 [0.38 sec, led 10] middle clear
  0b0011001000000001, //[0.38 sec, led 9, led 0]
  0b0011000100000000, //[0.38 sec, led 8]
  0b0011000010010000, //frame 7 [0.38 sec, led 4,7]
  0b0010010000000000, //frame 8 [0.25 sec, led 10] top clear
  0b0010001000000110, //[0.25 sec, led 1,2,9]
  0b0010000100001000, //[0.25 sec, led 3,8]
  0b0010000011100000  //frame 11 [0.25 sec, led 5,6,7]
};*/
const word frames_flappy[FRAME_COUNT_FLAPPY]={//reworked with positive logic: hitting a '1' with the paddle is life++ (WAS life--), also increase make 0.38 sec min frame time to slow animation
  0b0101010000000000, //frame 1 [0.62 sec, OFF] bottom life++ --> led 10
  0b0101001000000000, //[0.62 sec, led 0, 1, 2] --> led 9
  0b0101000100000000, //[0.62 sec, led 3] --> led 8
  0b0101000010000000, //frame 3 [0.62 sec, led 4, 5, 6] --> led 7
  0b0100000000000000, //frame 4 [0.5 sec, led 10] middle life++ --> OFF
  0b0100000000000110, //[0.5 sec, led 9, led 0] --> led 1,2
  0b0100000000001000, //[0.5 sec, led 8] --> led 3
  0b0100000001100000, //frame 7 [0.5 sec, led 4,7] --> led 5,6
  0b0011000000000000, //frame 8 [0.38 sec, led 10] top life++ --> OFF
  0b0011000000000001, //[0.38 sec, led 1,2,9] --> led 0
  0b0011000000000000, //[0.38 sec, led 3,8] --> OFF
  0b0011000000010000  //frame 11 [0.38 sec, led 5,6,7] --> led 4
};
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

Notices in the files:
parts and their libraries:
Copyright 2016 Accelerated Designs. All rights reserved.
